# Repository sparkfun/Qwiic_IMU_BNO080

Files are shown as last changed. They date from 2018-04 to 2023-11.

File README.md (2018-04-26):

SparkFun Qwiic VR IMU with the BNO080
========================================

SparkFun Inertial Measurement Unit - BNO080

[*SparkX IMU BNO080 (BOB-14686)*](https://www.sparkfun.com/products/14686)

The BNO080/BNO085 IMU has a combination triple axis accelerometer/gyro/magnetometer packaged with an ARM Cortex M0+ running powerful algorithms. This enables the BNO080 Inertial Measurement Unit (IMU) to produce accurate rotation vector headings with an error of 5 degrees or less. It's what we've been waiting for: all the sensor data is combined into meaningful, accurate IMU information.

This IC was designed to be implemented in Android based cellular phones to handle all the computations necessary for virtual reality goggles using only your phone. The sensor is quite powerful but with power comes a complex interface. We've written an I<sup>2</sup>C based library that provides the rotation vector (the reading most folks want from an IMU) as well as raw acceleration, gyro, and magnetometer readings. The sensor is capable of communicating over SPI and UART as well!

In addition the BNO080 IMU provides a built-in step counter, tap detector, activity classifier (are you running, walking, or sitting still?), and a shake detector. We are duly impressed.

Repository Contents
-------------------

* **/Documents** - Datasheets
* **/Firmware** - Just the test routine for the testjig. Please see the [BNO080/BNO085 library](https://github.com/sparkfun/SparkFun_BNO080_Arduino_Library) for a large number of examples.
* **/Hardware** - Eagle design files (.brd, .sch)
* **/Software** - Processing Example showing how to manipulate graphics using quaternions

Library
--------------
* **[Arduino Library](https://github.com/sparkfun/SparkFun_BNO080_Arduino_Library)** - Library for reading Quaternions, raw accel/gyro/mag, reading activity classifier, advanced configuration, etc.

License Information
-------------------

This product is _**open source**_! 

Please review the LICENSE.md file for license information. 

If you have any questions or concerns on licensing, please contact techsupport@sparkfun.com.

Please use, reuse, and modify these files as you see fit. Please maintain attribution to SparkFun Electronics and release anyThing Development Board derivative under the same license.

Distributed as-is; no warranty is given.

- Your friends at SparkFun.

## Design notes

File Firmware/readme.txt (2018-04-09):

Please download the Arduino library using the library manager for lots of easy to use examples: https://github.com/sparkfun/SparkFun_BNO080_Arduino_Library

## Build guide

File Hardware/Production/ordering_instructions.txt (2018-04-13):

panel size, 262x143mm
PCB thickness, 1.6mm
number of layers, 2
soldermask color, Red
silkscreen color, White
oz copper, 1oz
finish, HASL lead free
stencils, top+bottom

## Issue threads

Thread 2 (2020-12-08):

Python library

JonnyTech, 2020-12-08:
I want to use this board connected to the I2C bus on a Raspberry Pi - is there a Python library available?

mcberry23, 2021-01-24:
This library developed by Adafruit also works on the SparkFun breakout: https://github.com/adafruit/Adafruit_CircuitPython_BNO08x

JonnyTech, 2021-01-24:
Thank you.

Closed 2021-01-24.

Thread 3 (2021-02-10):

Add PWR LED jumper

adamgarbo, 2021-02-10:
Hi folks,

If this board ever gets an upgrade to the Hillcrest (now CEVA) BNO085 or sees a hardware revision, it'd be great to have a jumper added to disable the power LED. I suspect this board was originally designed before this was standard practice at SparkFun.

Cheers,
Adam

adamgarbo, 2021-12-23:
Closing this issue as it is anticipated that any future BNO080/85 boards will include the appropriate LED jumper, which has become part of the standard design of almost all SparkFun products.

Closed 2021-12-23.

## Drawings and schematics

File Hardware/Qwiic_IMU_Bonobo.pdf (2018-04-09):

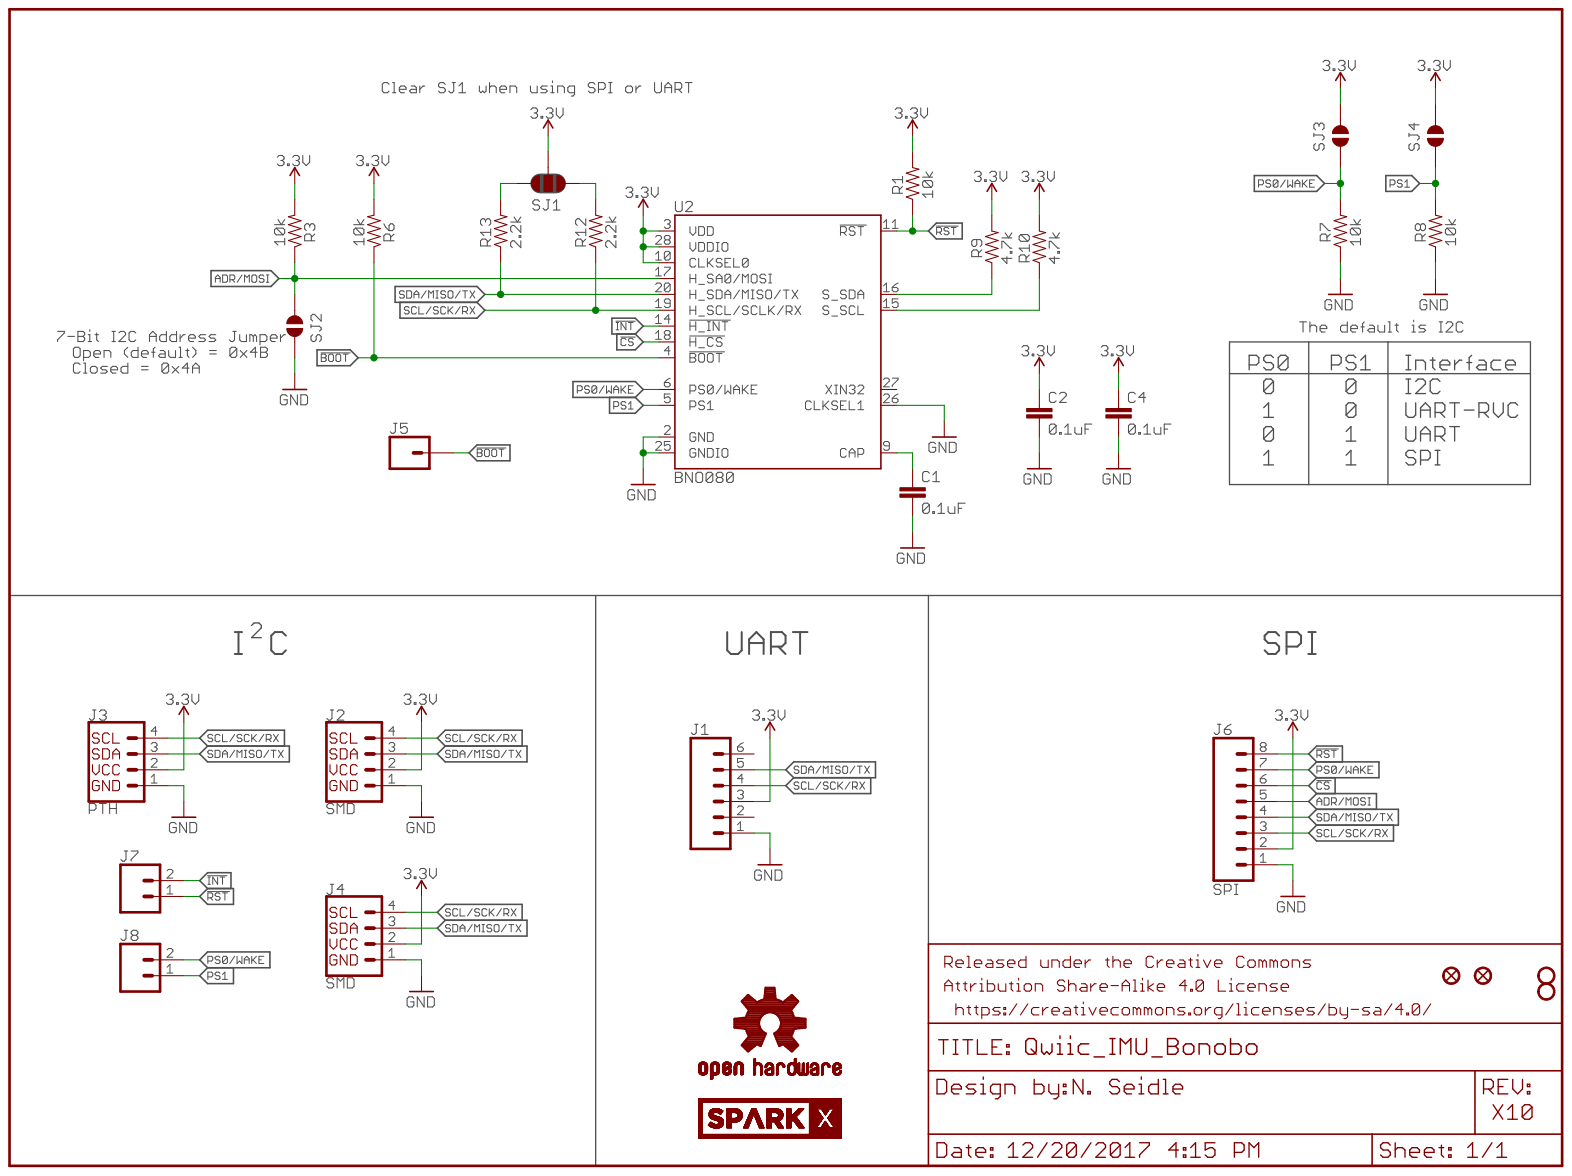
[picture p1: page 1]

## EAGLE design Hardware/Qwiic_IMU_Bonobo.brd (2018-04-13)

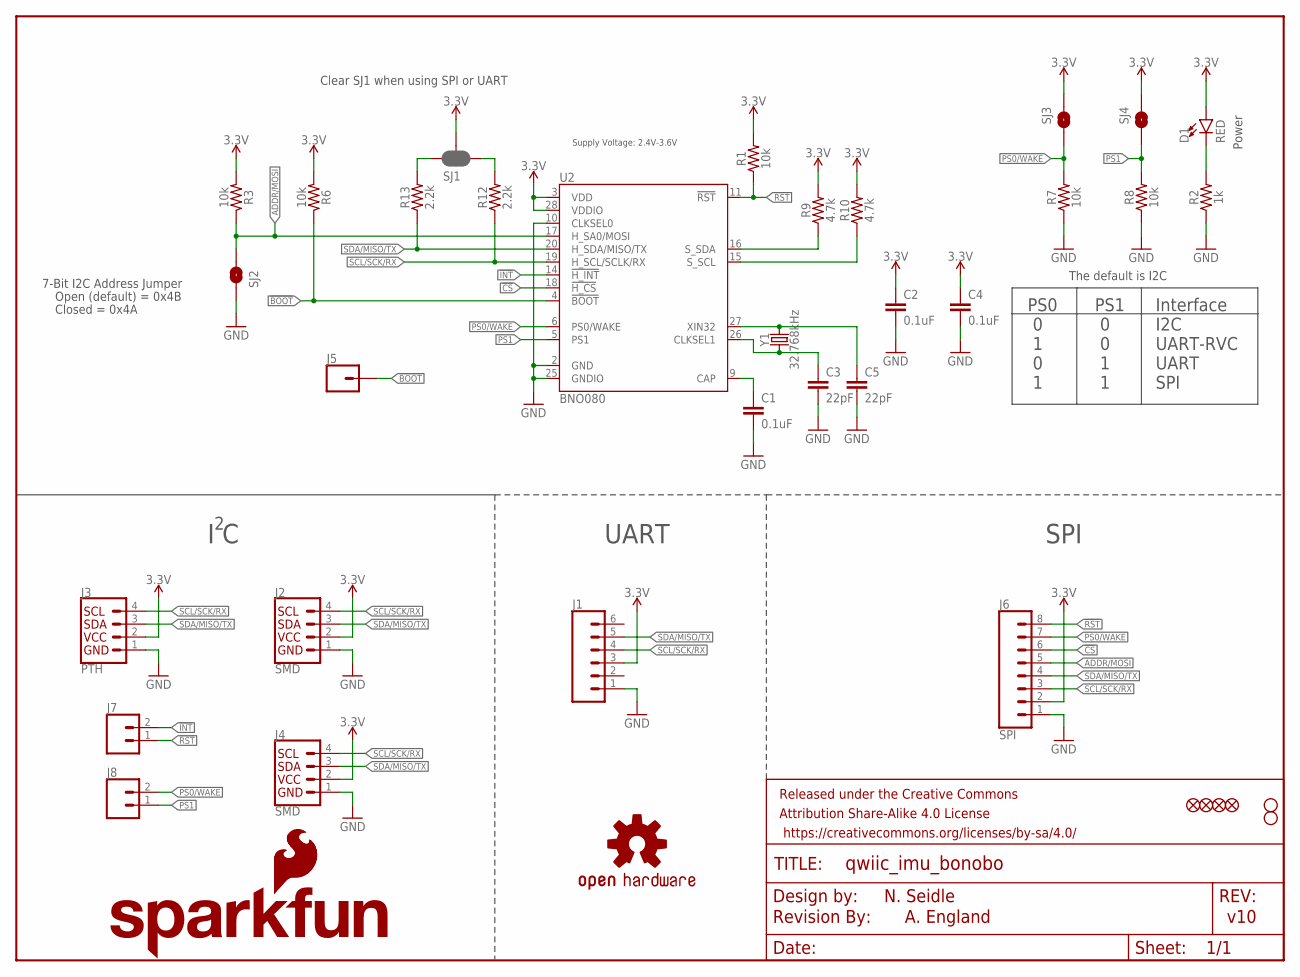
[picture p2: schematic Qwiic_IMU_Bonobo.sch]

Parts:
C1, C2, C4: 0.1uF; 0603
C3, C5: 22pF; 0603
D1: RED; LED-0603
FRAME1: FRAME-LETTER; CREATIVE_COMMONS
J1: CONN_06NO_SILK_FEMALE_PTH; 1X06_NO_SILK
J2, J4: SMD; 1X04_1MM_RA
J3: PTH; 1X04_NO_SILK
J5: CONN_01PTH_NO_SILK_YES_STOP; 1X01_NO_SILK
J6: SPI; 1X08_NO_SILK
J7, J8: CONN_021X02_NO_SILK; 1X02_NO_SILK
JP1, JP2, JP5, JP6: FIDUCIALUFIDUCIAL; MICRO-FIDUCIAL
JP3, JP4: STAND-OFF
LOGO1: OSHW-LOGOMINI; OSHW-LOGO-MINI
LOGO2: REVISION
LOGO4: SFE_LOGO_FLAME.1_INCH; SFE_LOGO_FLAME_.1
LOGO5: SFE_LOGO_NAME_FLAME.1_INCH; SFE_LOGO_NAME_FLAME_.1
R1, R3, R6, R7, R8: 10k; 0603
R2: 1k; 0603
R9, R10: 4.7k; 0603
R12, R13: 2.2k; 0603
SJ1: JUMPER-SMT_3_2-NC_PASTE_SILK; SMT-JUMPER_3_2-NC_PASTE_SILK
SJ2, SJ3, SJ4: SOLDERJUMPERNO; SJ_2S-NO
U2: BNO080; LGA-28
Y1: 32.768kHz; CRYSTAL-SMD-3.2X1.5MM

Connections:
3.3V: C2.1, C4.1, D1.A, J1.3, J2.2 (VCC), J3.2 (VCC), J4.2 (VCC), J6.2, R1.2, R3.2, R6.2, R9.2, R10.2, SJ1.2, SJ3.1, SJ4.1, U2.3 (VDD), U2.28 (VDDIO)
!BOOT: J5.1, R6.1, U2.4 (!BOOT)
!CS: J6.6, U2.18 (!H_CS)
!INT: J7.2, U2.14 (!H_INT)
!RST: J6.8, J7.1, R1.1, U2.11 (!RST)
ADDR/MOSI: J6.5, R3.1, SJ2.2, U2.17 (H_SA0/MOSI)
CAP: C1.1, U2.9 (CAP)
GND: C1.2, C2.2, C3.2, C4.2, C5.2, J1.1, J2.1 (GND), J3.1 (GND), J4.1 (GND), J6.1, R2.1, R7.1, R8.1, SJ2.1, U2.2 (GND), U2.10 (CLKSEL0), U2.25 (GNDIO)
unnamed: C5.1, U2.27 (XIN32), Y1.P$2 (2)
unnamed: C3.1, U2.26 (CLKSEL1), Y1.P$1 (1)
unnamed: D1.C, R2.2
PS0/WAKE: J6.7, J8.2, R7.2, SJ3.2, U2.6 (PS0/WAKE)
PS1: J8.1, R8.2, SJ4.2, U2.5 (PS1)
SCL/SCK/RX: J1.4, J2.4 (SCL), J3.4 (SCL), J4.4 (SCL), J6.3, R12.1, U2.19 (H_SCL/SCLK/RX)
SCL_PU: R12.2, SJ1.1
SDA/MISO/TX: J1.5, J2.3 (SDA), J3.3 (SDA), J4.3 (SDA), J6.4, R13.1, U2.20 (H_SDA/MISO/TX)
SDA_PU: R13.2, SJ1.3
S_SCL: R10.1, U2.15 (S_SCL)
S_SDA: R9.1, U2.16 (S_SDA)

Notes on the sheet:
N. Seidle
v10
7-Bit I2C Address Jumper
Closed = 0x4A
Open (default) = 0x4B
PS0 0 1 0 1
PS1 0 0 1 1
Interface I2C UART-RVC UART SPI
The default is I2C
Clear SJ1 when using SPI or UART
I C
UART
SPI
Power
A. England
Supply Voltage: 2.4V-3.6V

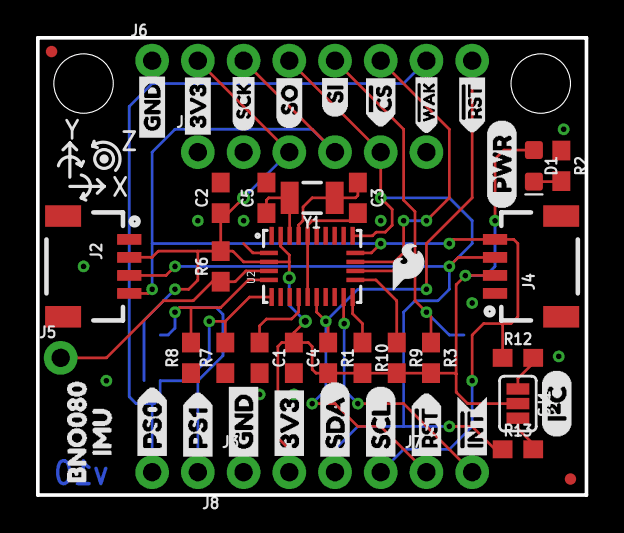
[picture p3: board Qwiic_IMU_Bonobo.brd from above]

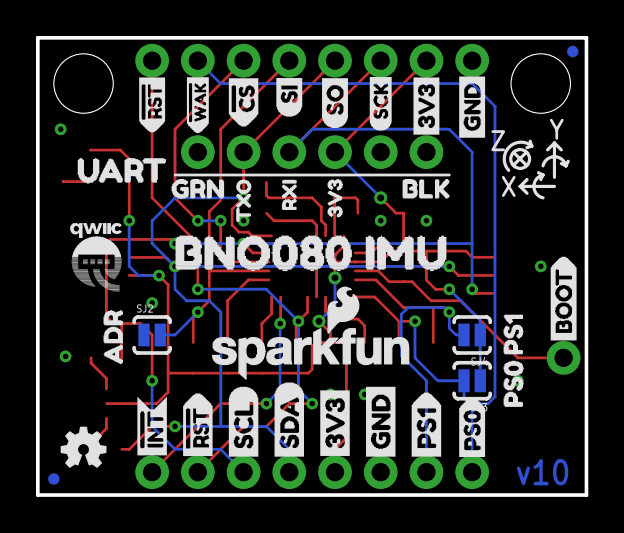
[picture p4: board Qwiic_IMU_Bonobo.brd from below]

Board: 2 copper layers, 30.5 x 25.4 mm, 89 parts (35 on the bottom side), 19 nets.

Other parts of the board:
U$1: (PWR)
U$2: BOOT2
U$3, U$4: #RST>
U$5, U$6: SCL
U$7, U$8: SDA
U$9, U$10: 3V3
U$11, U$50: 3V30
U$12, U$13: SCK0
U$14: PS03
U$15, U$16: GND
U$17, U$18: SI1
U$19, U$20: #WAK6
U$21: 3V32
U$22: RXI1
U$23: (I_SUPER2_C)
U$25, U$26: #INT0
U$27, U$28: PS14
U$29: PS05
U$30: ADR0
U$33: PS114
U$34: PS015
U$35: TXO0
U$39: UART8
U$40: GRN10
U$41: BLK9
U$42, U$43: GND1
U$44: BNO080_IMU11
U$46: BNO08012
U$47: IMU13
U$49, U$51: #RST7
U$52, U$53: #CS3
U$54, U$55: SO0
U$59: QWIIC#LABEL#FULL#M#PNG

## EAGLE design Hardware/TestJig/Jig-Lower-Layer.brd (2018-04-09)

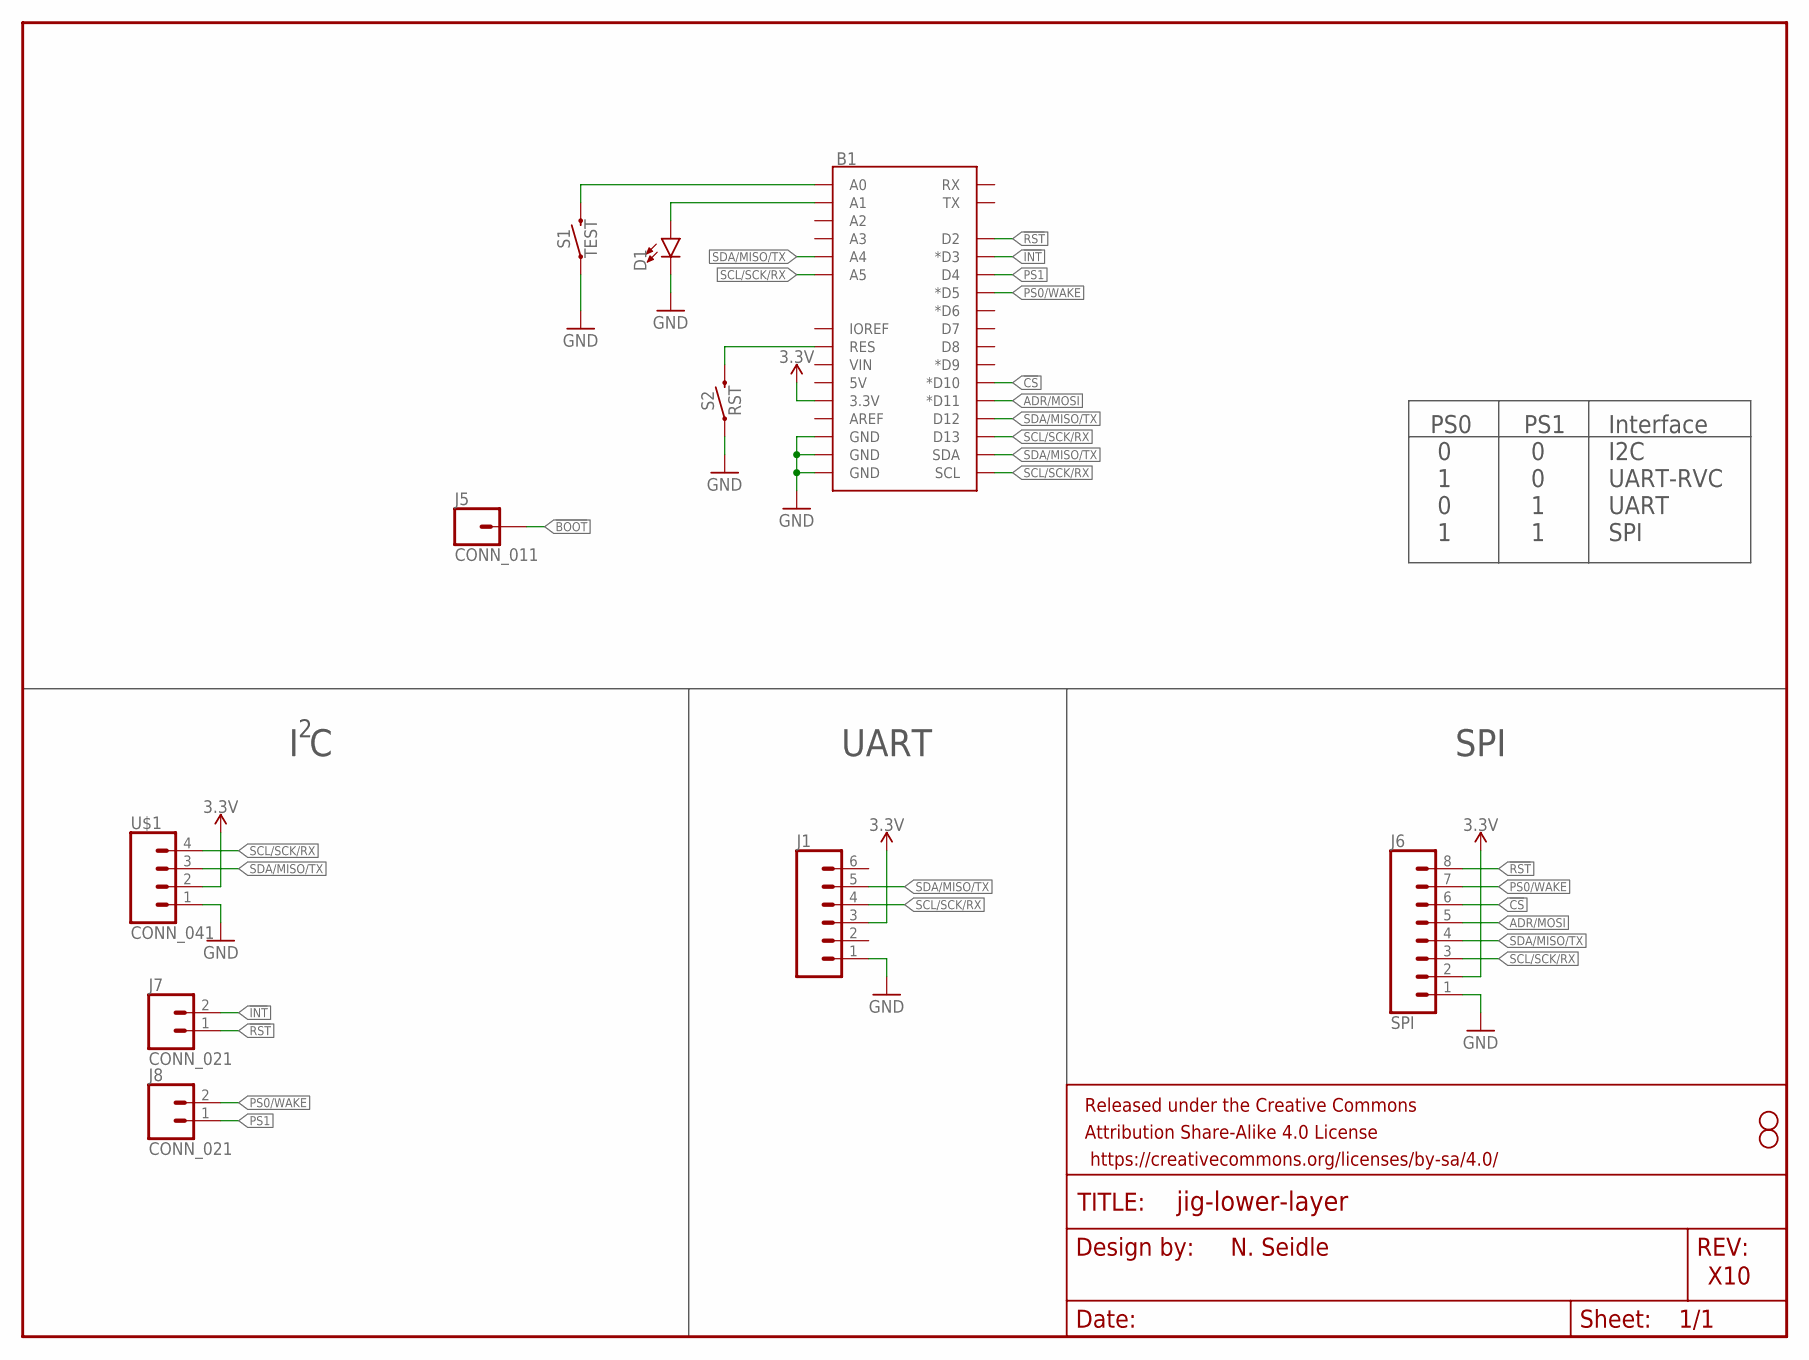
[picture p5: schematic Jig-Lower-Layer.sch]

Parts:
B1: ARDUINO_UNO_R3_SHIELDBASIC; UNO_R3_SHIELD
D1: LED5MM; LED_5MM
FRAME1: FRAME-LETTER; CREATIVE_COMMONS
J1: CONN_061; 1X06
J5: CONN_011; 1X01
J6: SPI; 1X08
J7, J8: CONN_021; 1X02
JP3, JP4: STAND-OFF
S1: TEST; TACTILE_SWITCH_PTH_12MM
S2: RST; TACTILE_SWITCH_PTH_12MM
U$1: CONN_041; 1X04

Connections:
3.3V: B1.3.3V, J1.3, J6.2, U$1.2
!BOOT: J5.1
!CS: B1.D10 (*D10), J6.6
!INT: B1.D3 (*D3), J7.2
!RST: B1.D2, J6.8, J7.1
ADR/MOSI: B1.D11 (*D11), J6.5
GND: B1.GND@0 (GND), B1.GND@1 (GND), B1.GND@2 (GND), D1.K (C), J1.1, J6.1, S1.1, S2.1, U$1.1
unnamed: B1.A0, S1.3 (2)
unnamed: B1.A1, D1.A
unnamed: B1.RES, S2.3 (2)
PS0/WAKE: B1.D5 (*D5), J6.7, J8.2
PS1: B1.D4, J8.1
SCL/SCK/RX: B1.A5, B1.D13, B1.SCL, J1.4, J6.3, U$1.4
SDA/MISO/TX: B1.A4, B1.D12, B1.SDA, J1.5, J6.4, U$1.3

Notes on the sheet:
N. Seidle
X10
PS0 0 1 0 1
PS1 0 0 1 1
Interface I2C UART-RVC UART SPI
I C
UART
SPI

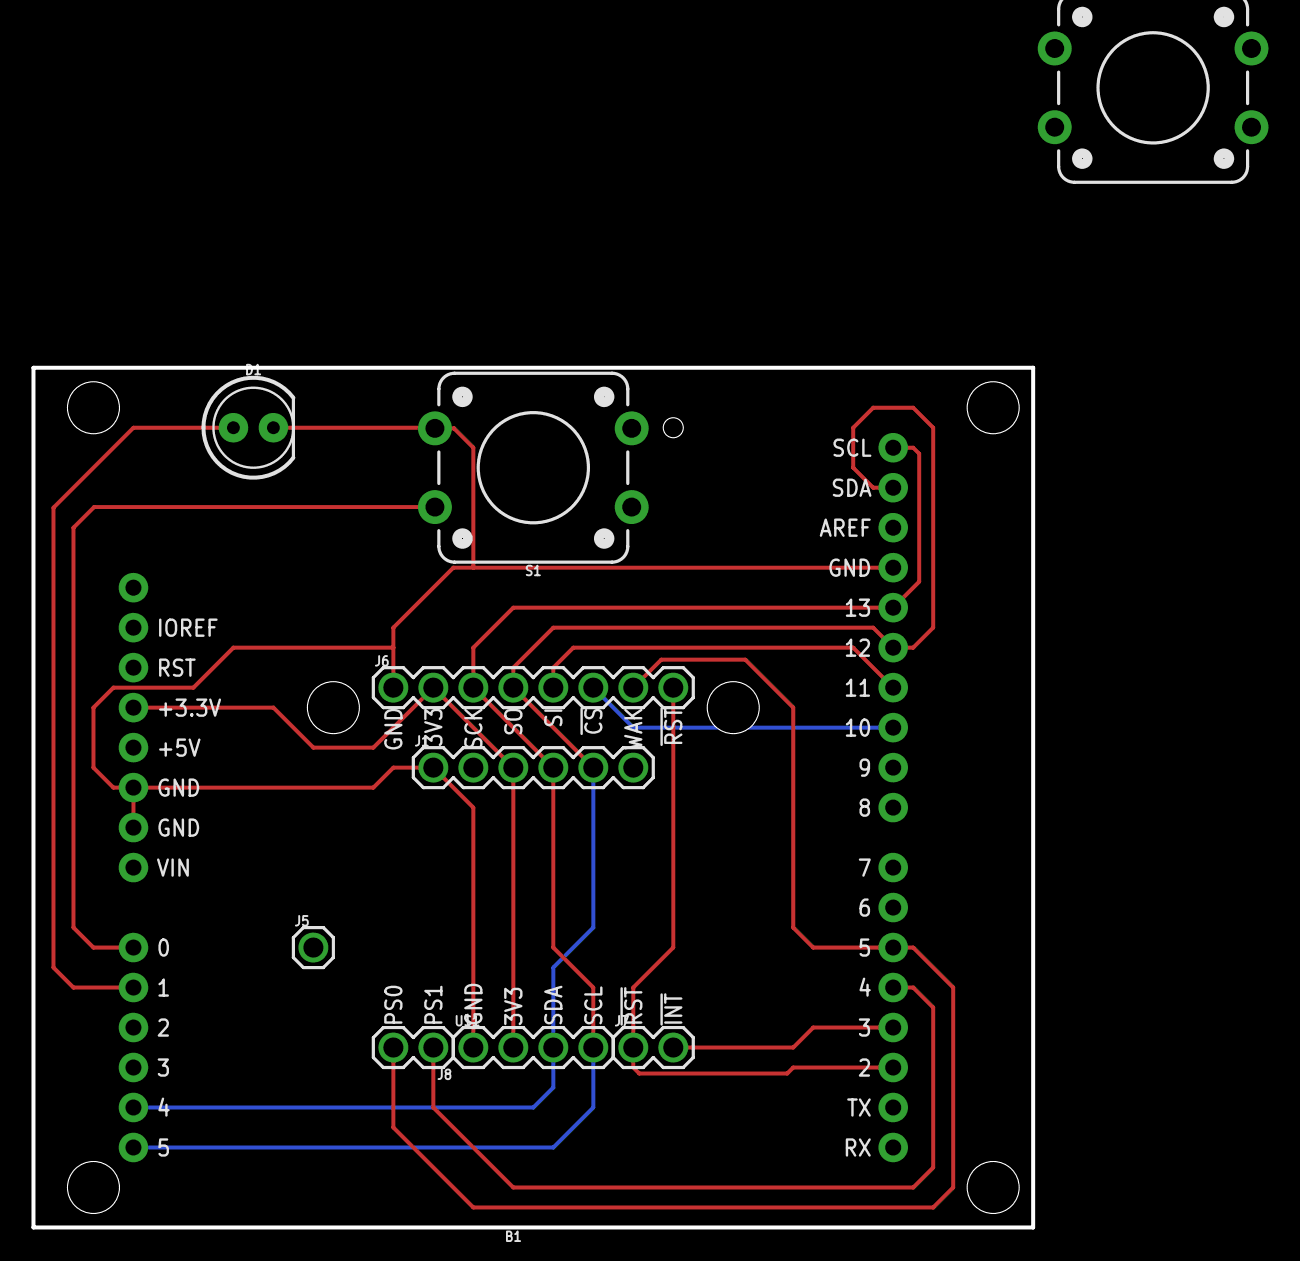
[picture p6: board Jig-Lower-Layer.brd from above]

Board: 2 copper layers, 63.5 x 54.6 mm, 17 parts (0 on the bottom side), 13 nets.

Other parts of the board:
JP1, JP2, JP5, JP6: STAND-OFF

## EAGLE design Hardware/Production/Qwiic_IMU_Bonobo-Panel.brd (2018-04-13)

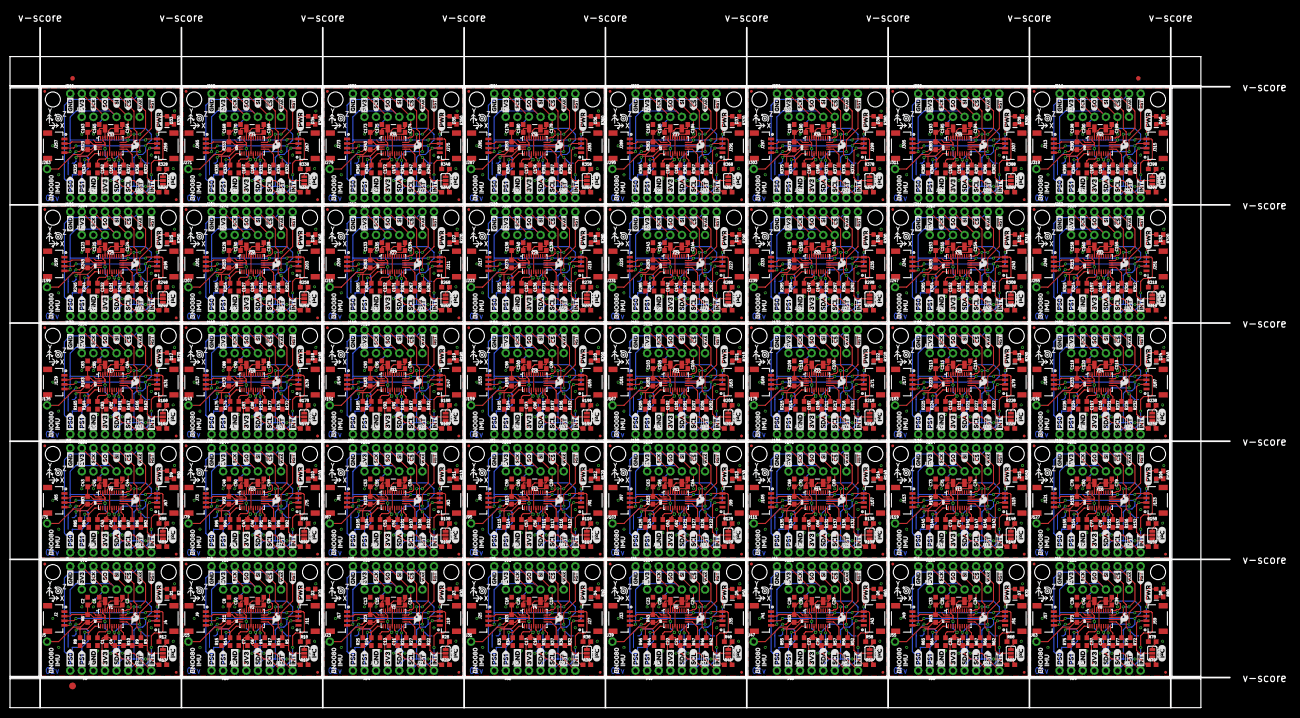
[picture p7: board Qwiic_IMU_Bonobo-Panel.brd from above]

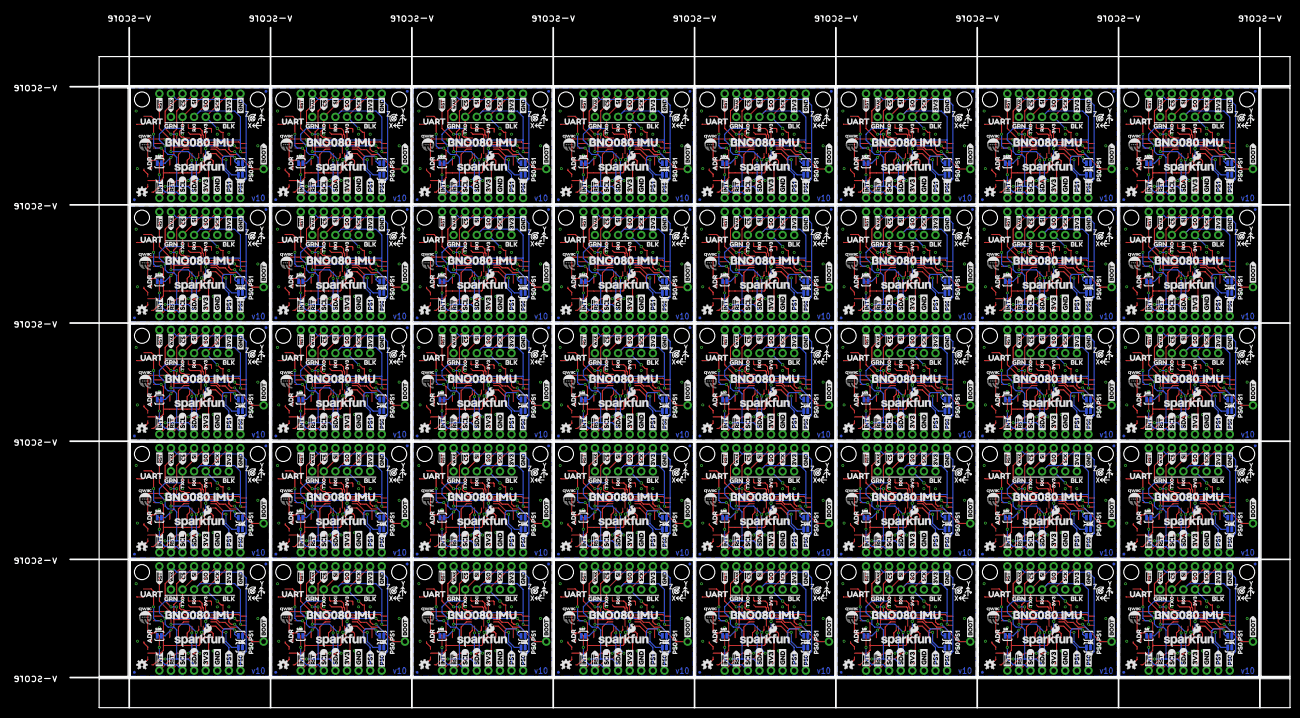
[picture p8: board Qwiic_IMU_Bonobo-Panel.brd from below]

Board: 2 copper layers, 267.5 x 149.1 mm, 3483 parts (1400 on the bottom side), 760 nets.

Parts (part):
C1, C2, C4, C6, C7, C8, C11, C12, C13, C16, C17, C18, C21, C22, C23, C26, C27, C28, C31, C32, C33, C36, C37, C38, C41, C42, C43, C46, C47, C48, C51, C52, C53, C56, C57, C58, C61, C62, C63, C66, C67, C68, C71, C72, C73, C76, C77, C78, C81, C82, C83, C86, C87, C88, C91, C92, C93, C96, C97, C98, C101, C102, C103, C106, C107, C108, C111, C112, C113, C116, C117, C118, C121, C122, C123, C126, C127, C128, C131, C132, C133, C136, C137, C138, C141, C142, C143, C146, C147, C148, C151, C152, C153, C156, C157, C158, C161, C162, C163, C166, C167, C168, C171, C172, C173, C176, C177, C178, C181, C182, C183, C186, C187, C188, C191, C192, C193, C196, C197, C198: 0.1uF; 0603
C3, C5, C9, C10, C14, C15, C19, C20, C24, C25, C29, C30, C34, C35, C39, C40, C44, C45, C49, C50, C54, C55, C59, C60, C64, C65, C69, C70, C74, C75, C79, C80, C84, C85, C89, C90, C94, C95, C99, C100, C104, C105, C109, C110, C114, C115, C119, C120, C124, C125, C129, C130, C134, C135, C139, C140, C144, C145, C149, C150, C154, C155, C159, C160, C164, C165, C169, C170, C174, C175, C179, C180, C184, C185, C189, C190, C194, C195, C199, C200: 22pF; 0603
D1, D2, D3, D4, D5, D6, D7, D8, D9, D10, D11, D12, D13, D14, D15, D16, D17, D18, D19, D20, D21, D22, D23, D24, D25, D26, D27, D28, D29, D30, D31, D32, D33, D34, D35, D36, D37, D38, D39, D40: RED; LED-0603
E$1, E$2: FIDUCIAL-1X2
E$3: FIDUCIAL-1.5X3
J1, J14, J22, J30, J38, J46, J54, J62, J70, J78, J86, J94, J102, J110, J118, J126, J134, J142, J150, J158, J166, J174, J182, J190, J198, J206, J214, J222, J230, J238, J246, J254, J262, J270, J278, J286, J294, J302, J310, J318: 1X06_NO_SILK
J2, J4, J9, J11, J17, J19, J25, J27, J33, J35, J41, J43, J49, J51, J57, J59, J65, J67, J73, J75, J81, J83, J89, J91, J97, J99, J105, J107, J113, J115, J121, J123, J129, J131, J137, J139, J145, J147, J153, J155, J161, J163, J169, J171, J177, J179, J185, J187, J193, J195, J201, J203, J209, J211, J217, J219, J225, J227, J233, J235, J241, J243, J249, J251, J257, J259, J265, J267, J273, J275, J281, J283, J289, J291, J297, J299, J305, J307, J313, J315: SMD; 1X04_1MM_RA
J3, J10, J18, J26, J34, J42, J50, J58, J66, J74, J82, J90, J98, J106, J114, J122, J130, J138, J146, J154, J162, J170, J178, J186, J194, J202, J210, J218, J226, J234, J242, J250, J258, J266, J274, J282, J290, J298, J306, J314: PTH; 1X04_NO_SILK
J5, J15, J23, J31, J39, J47, J55, J63, J71, J79, J87, J95, J103, J111, J119, J127, J135, J143, J151, J159, J167, J175, J183, J191, J199, J207, J215, J223, J231, J239, J247, J255, J263, J271, J279, J287, J295, J303, J311, J319: 1X01_NO_SILK
J6, J12, J20, J28, J36, J44, J52, J60, J68, J76, J84, J92, J100, J108, J116, J124, J132, J140, J148, J156, J164, J172, J180, J188, J196, J204, J212, J220, J228, J236, J244, J252, J260, J268, J276, J284, J292, J300, J308, J316: SPI; 1X08_NO_SILK
J7, J8, J13, J16, J21, J24, J29, J32, J37, J40, J45, J48, J53, J56, J61, J64, J69, J72, J77, J80, J85, J88, J93, J96, J101, J104, J109, J112, J117, J120, J125, J128, J133, J136, J141, J144, J149, J152, J157, J160, J165, J168, J173, J176, J181, J184, J189, J192, J197, J200, J205, J208, J213, J216, J221, J224, J229, J232, J237, J240, J245, J248, J253, J256, J261, J264, J269, J272, J277, J280, J285, J288, J293, J296, J301, J304, J309, J312, J317, J320: 1X02_NO_SILK
JP1, JP2, JP5, JP6, JP9, JP10, JP11, JP12, JP15, JP16, JP17, JP18, JP21, JP22, JP23, JP24, JP27, JP28, JP29, JP30, JP33, JP34, JP35, JP36, JP39, JP40, JP41, JP42, JP45, JP46, JP47, JP48, JP51, JP52, JP53, JP54, JP57, JP58, JP59, JP60, JP63, JP64, JP65, JP66, JP69, JP70, JP71, JP72, JP75, JP76, JP77, JP78, JP81, JP82, JP83, JP84, JP87, JP88, JP89, JP90, JP93, JP94, JP95, JP96, JP99, JP100, JP101, JP102, JP105, JP106, JP107, JP108, JP111, JP112, JP113, JP114, JP117, JP118, JP119, JP120, JP123, JP124, JP125, JP126, JP129, JP130, JP131, JP132, JP135, JP136, JP137, JP138, JP141, JP142, JP143, JP144, JP147, JP148, JP149, JP150, JP153, JP154, JP155, JP156, JP159, JP160, JP161, JP162, JP165, JP166, JP167, JP168, JP171, JP172, JP173, JP174, JP177, JP178, JP179, JP180, JP183, JP184, JP185, JP186, JP189, JP190, JP191, JP192, JP195, JP196, JP197, JP198, JP201, JP202, JP203, JP204, JP207, JP208, JP209, JP210, JP213, JP214, JP215, JP216, JP219, JP220, JP221, JP222, JP225, JP226, JP227, JP228, JP231, JP232, JP233, JP234, JP237, JP238, JP239, JP240: FIDUCIALUFIDUCIAL; MICRO-FIDUCIAL
JP3, JP4, JP7, JP8, JP13, JP14, JP19, JP20, JP25, JP26, JP31, JP32, JP37, JP38, JP43, JP44, JP49, JP50, JP55, JP56, JP61, JP62, JP67, JP68, JP73, JP74, JP79, JP80, JP85, JP86, JP91, JP92, JP97, JP98, JP103, JP104, JP109, JP110, JP115, JP116, JP121, JP122, JP127, JP128, JP133, JP134, JP139, JP140, JP145, JP146, JP151, JP152, JP157, JP158, JP163, JP164, JP169, JP170, JP175, JP176, JP181, JP182, JP187, JP188, JP193, JP194, JP199, JP200, JP205, JP206, JP211, JP212, JP217, JP218, JP223, JP224, JP229, JP230, JP235, JP236: STAND-OFF
LOGO1, LOGO2, LOGO7, LOGO10, LOGO13, LOGO16, LOGO19, LOGO22, LOGO25, LOGO28, LOGO31, LOGO34, LOGO37, LOGO40, LOGO43, LOGO46, LOGO49, LOGO52, LOGO55, LOGO58, LOGO61, LOGO64, LOGO67, LOGO70, LOGO73, LOGO76, LOGO79, LOGO82, LOGO85, LOGO88, LOGO91, LOGO94, LOGO97, LOGO100, LOGO103, LOGO106, LOGO109, LOGO112, LOGO115, LOGO118: OSHW-LOGOMINI; OSHW-LOGO-MINI
LOGO3, LOGO4, LOGO8, LOGO11, LOGO14, LOGO17, LOGO20, LOGO23, LOGO26, LOGO29, LOGO32, LOGO35, LOGO38, LOGO41, LOGO44, LOGO47, LOGO50, LOGO53, LOGO56, LOGO59, LOGO62, LOGO65, LOGO68, LOGO71, LOGO74, LOGO77, LOGO80, LOGO83, LOGO86, LOGO89, LOGO92, LOGO95, LOGO98, LOGO101, LOGO104, LOGO107, LOGO110, LOGO113, LOGO116, LOGO119: SFE_LOGO_FLAME.1_INCH; SFE_LOGO_FLAME_.1
LOGO5, LOGO6, LOGO9, LOGO12, LOGO15, LOGO18, LOGO21, LOGO24, LOGO27, LOGO30, LOGO33, LOGO36, LOGO39, LOGO42, LOGO45, LOGO48, LOGO51, LOGO54, LOGO57, LOGO60, LOGO63, LOGO66, LOGO69, LOGO72, LOGO75, LOGO78, LOGO81, LOGO84, LOGO87, LOGO90, LOGO93, LOGO96, LOGO99, LOGO102, LOGO105, LOGO108, LOGO111, LOGO114, LOGO117, LOGO120: SFE_LOGO_NAME_FLAME.1_INCH; SFE_LOGO_NAME_FLAME_.1
R1, R3, R4, R5, R6, R7, R8, R11, R14, R15, R21, R22, R23, R24, R25, R31, R32, R33, R34, R35, R41, R42, R43, R44, R45, R51, R52, R53, R54, R55, R61, R62, R63, R64, R65, R71, R72, R73, R74, R75, R81, R82, R83, R84, R85, R91, R92, R93, R94, R95, R101, R102, R103, R104, R105, R111, R112, R113, R114, R115, R121, R122, R123, R124, R125, R131, R132, R133, R134, R135, R141, R142, R143, R144, R145, R151, R152, R153, R154, R155, R161, R162, R163, R164, R165, R171, R172, R173, R174, R175, R181, R182, R183, R184, R185, R191, R192, R193, R194, R195, R201, R202, R203, R204, R205, R211, R212, R213, R214, R215, R221, R222, R223, R224, R225, R231, R232, R233, R234, R235, R241, R242, R243, R244, R245, R251, R252, R253, R254, R255, R261, R262, R263, R264, R265, R271, R272, R273, R274, R275, R281, R282, R283, R284, R285, R291, R292, R293, R294, R295, R301, R302, R303, R304, R305, R311, R312, R313, R314, R315, R321, R322, R323, R324, R325, R331, R332, R333, R334, R335, R341, R342, R343, R344, R345, R351, R352, R353, R354, R355, R361, R362, R363, R364, R365, R371, R372, R373, R374, R375, R381, R382, R383, R384, R385, R391, R392, R393, R394, R395: 10k; 0603
R2, R20, R30, R40, R50, R60, R70, R80, R90, R100, R110, R120, R130, R140, R150, R160, R170, R180, R190, R200, R210, R220, R230, R240, R250, R260, R270, R280, R290, R300, R310, R320, R330, R340, R350, R360, R370, R380, R390, R400: 1k; 0603
R9, R10, R16, R17, R26, R27, R36, R37, R46, R47, R56, R57, R66, R67, R76, R77, R86, R87, R96, R97, R106, R107, R116, R117, R126, R127, R136, R137, R146, R147, R156, R157, R166, R167, R176, R177, R186, R187, R196, R197, R206, R207, R216, R217, R226, R227, R236, R237, R246, R247, R256, R257, R266, R267, R276, R277, R286, R287, R296, R297, R306, R307, R316, R317, R326, R327, R336, R337, R346, R347, R356, R357, R366, R367, R376, R377, R386, R387, R396, R397: 4.7k; 0603
R12, R13, R18, R19, R28, R29, R38, R39, R48, R49, R58, R59, R68, R69, R78, R79, R88, R89, R98, R99, R108, R109, R118, R119, R128, R129, R138, R139, R148, R149, R158, R159, R168, R169, R178, R179, R188, R189, R198, R199, R208, R209, R218, R219, R228, R229, R238, R239, R248, R249, R258, R259, R268, R269, R278, R279, R288, R289, R298, R299, R308, R309, R318, R319, R328, R329, R338, R339, R348, R349, R358, R359, R368, R369, R378, R379, R388, R389, R398, R399: 2.2k; 0603
SJ1, SJ8, SJ12, SJ16, SJ20, SJ24, SJ28, SJ32, SJ36, SJ40, SJ44, SJ48, SJ52, SJ56, SJ60, SJ64, SJ68, SJ72, SJ76, SJ80, SJ84, SJ88, SJ92, SJ96, SJ100, SJ104, SJ108, SJ112, SJ116, SJ120, SJ124, SJ128, SJ132, SJ136, SJ140, SJ144, SJ148, SJ152, SJ156, SJ160: SMT-JUMPER_3_2-NC_PASTE_SILK
SJ2, SJ3, SJ4, SJ5, SJ6, SJ7, SJ9, SJ10, SJ11, SJ13, SJ14, SJ15, SJ17, SJ18, SJ19, SJ21, SJ22, SJ23, SJ25, SJ26, SJ27, SJ29, SJ30, SJ31, SJ33, SJ34, SJ35, SJ37, SJ38, SJ39, SJ41, SJ42, SJ43, SJ45, SJ46, SJ47, SJ49, SJ50, SJ51, SJ53, SJ54, SJ55, SJ57, SJ58, SJ59, SJ61, SJ62, SJ63, SJ65, SJ66, SJ67, SJ69, SJ70, SJ71, SJ73, SJ74, SJ75, SJ77, SJ78, SJ79, SJ81, SJ82, SJ83, SJ85, SJ86, SJ87, SJ89, SJ90, SJ91, SJ93, SJ94, SJ95, SJ97, SJ98, SJ99, SJ101, SJ102, SJ103, SJ105, SJ106, SJ107, SJ109, SJ110, SJ111, SJ113, SJ114, SJ115, SJ117, SJ118, SJ119, SJ121, SJ122, SJ123, SJ125, SJ126, SJ127, SJ129, SJ130, SJ131, SJ133, SJ134, SJ135, SJ137, SJ138, SJ139, SJ141, SJ142, SJ143, SJ145, SJ146, SJ147, SJ149, SJ150, SJ151, SJ153, SJ154, SJ155, SJ157, SJ158, SJ159: SJ_2S-NO
U1, U2, U3, U4, U5, U6, U7, U8, U9, U10, U11, U12, U13, U14, U15, U16, U17, U18, U19, U20, U21, U22, U23, U24, U25, U26, U27, U28, U29, U30, U31, U32, U33, U34, U35, U36, U37, U38, U39, U40: BNO080; LGA-28
U$1, U$95, U$143, U$191, U$239, U$287, U$335, U$383, U$431, U$479, U$527, U$575, U$623, U$671, U$719, U$767, U$815, U$863, U$911, U$959, U$1007, U$1055, U$1103, U$1151, U$1199, U$1247, U$1295, U$1343, U$1391, U$1439, U$1487, U$1535, U$1583, U$1631, U$1679, U$1727, U$1775, U$1823, U$1871, U$1919: (PWR)
U$2, U$94, U$142, U$190, U$238, U$286, U$334, U$382, U$430, U$478, U$526, U$574, U$622, U$670, U$718, U$766, U$814, U$862, U$910, U$958, U$1006, U$1054, U$1102, U$1150, U$1198, U$1246, U$1294, U$1342, U$1390, U$1438, U$1486, U$1534, U$1582, U$1630, U$1678, U$1726, U$1774, U$1822, U$1870, U$1918: BOOT2
U$3, U$4, U$24, U$31, U$97, U$98, U$145, U$146, U$193, U$194, U$241, U$242, U$289, U$290, U$337, U$338, U$385, U$386, U$433, U$434, U$481, U$482, U$529, U$530, U$577, U$578, U$625, U$626, U$673, U$674, U$721, U$722, U$769, U$770, U$817, U$818, U$865, U$866, U$913, U$914, U$961, U$962, U$1009, U$1010, U$1057, U$1058, U$1105, U$1106, U$1153, U$1154, U$1201, U$1202, U$1249, U$1250, U$1297, U$1298, U$1345, U$1346, U$1393, U$1394, U$1441, U$1442, U$1489, U$1490, U$1537, U$1538, U$1585, U$1586, U$1633, U$1634, U$1681, U$1682, U$1729, U$1730, U$1777, U$1778, U$1825, U$1826, U$1873, U$1874: #RST>
U$5, U$6, U$32, U$36, U$99, U$100, U$147, U$148, U$195, U$196, U$243, U$244, U$291, U$292, U$339, U$340, U$387, U$388, U$435, U$436, U$483, U$484, U$531, U$532, U$579, U$580, U$627, U$628, U$675, U$676, U$723, U$724, U$771, U$772, U$819, U$820, U$867, U$868, U$915, U$916, U$963, U$964, U$1011, U$1012, U$1059, U$1060, U$1107, U$1108, U$1155, U$1156, U$1203, U$1204, U$1251, U$1252, U$1299, U$1300, U$1347, U$1348, U$1395, U$1396, U$1443, U$1444, U$1491, U$1492, U$1539, U$1540, U$1587, U$1588, U$1635, U$1636, U$1683, U$1684, U$1731, U$1732, U$1779, U$1780, U$1827, U$1828, U$1875, U$1876: SCL
U$7, U$8, U$37, U$38, U$101, U$102, U$149, U$150, U$197, U$198, U$245, U$246, U$293, U$294, U$341, U$342, U$389, U$390, U$437, U$438, U$485, U$486, U$533, U$534, U$581, U$582, U$629, U$630, U$677, U$678, U$725, U$726, U$773, U$774, U$821, U$822, U$869, U$870, U$917, U$918, U$965, U$966, U$1013, U$1014, U$1061, U$1062, U$1109, U$1110, U$1157, U$1158, U$1205, U$1206, U$1253, U$1254, U$1301, U$1302, U$1349, U$1350, U$1397, U$1398, U$1445, U$1446, U$1493, U$1494, U$1541, U$1542, U$1589, U$1590, U$1637, U$1638, U$1685, U$1686, U$1733, U$1734, U$1781, U$1782, U$1829, U$1830, U$1877, U$1878: SDA
U$9, U$10, U$45, U$48, U$103, U$104, U$151, U$152, U$199, U$200, U$247, U$248, U$295, U$296, U$343, U$344, U$391, U$392, U$439, U$440, U$487, U$488, U$535, U$536, U$583, U$584, U$631, U$632, U$679, U$680, U$727, U$728, U$775, U$776, U$823, U$824, U$871, U$872, U$919, U$920, U$967, U$968, U$1015, U$1016, U$1063, U$1064, U$1111, U$1112, U$1159, U$1160, U$1207, U$1208, U$1255, U$1256, U$1303, U$1304, U$1351, U$1352, U$1399, U$1400, U$1447, U$1448, U$1495, U$1496, U$1543, U$1544, U$1591, U$1592, U$1639, U$1640, U$1687, U$1688, U$1735, U$1736, U$1783, U$1784, U$1831, U$1832, U$1879, U$1880: 3V3
U$11, U$50, U$73, U$74, U$121, U$122, U$169, U$170, U$217, U$218, U$265, U$266, U$313, U$314, U$361, U$362, U$409, U$410, U$457, U$458, U$505, U$506, U$553, U$554, U$601, U$602, U$649, U$650, U$697, U$698, U$745, U$746, U$793, U$794, U$841, U$842, U$889, U$890, U$937, U$938, U$985, U$986, U$1033, U$1034, U$1081, U$1082, U$1129, U$1130, U$1177, U$1178, U$1225, U$1226, U$1273, U$1274, U$1321, U$1322, U$1369, U$1370, U$1417, U$1418, U$1465, U$1466, U$1513, U$1514, U$1561, U$1562, U$1609, U$1610, U$1657, U$1658, U$1705, U$1706, U$1753, U$1754, U$1801, U$1802, U$1849, U$1850, U$1897, U$1898: 3V30
U$12, U$13, U$83, U$84, U$131, U$132, U$179, U$180, U$227, U$228, U$275, U$276, U$323, U$324, U$371, U$372, U$419, U$420, U$467, U$468, U$515, U$516, U$563, U$564, U$611, U$612, U$659, U$660, U$707, U$708, U$755, U$756, U$803, U$804, U$851, U$852, U$899, U$900, U$947, U$948, U$995, U$996, U$1043, U$1044, U$1091, U$1092, U$1139, U$1140, U$1187, U$1188, U$1235, U$1236, U$1283, U$1284, U$1331, U$1332, U$1379, U$1380, U$1427, U$1428, U$1475, U$1476, U$1523, U$1524, U$1571, U$1572, U$1619, U$1620, U$1667, U$1668, U$1715, U$1716, U$1763, U$1764, U$1811, U$1812, U$1859, U$1860, U$1907, U$1908: SCK0
U$14, U$89, U$137, U$185, U$233, U$281, U$329, U$377, U$425, U$473, U$521, U$569, U$617, U$665, U$713, U$761, U$809, U$857, U$905, U$953, U$1001, U$1049, U$1097, U$1145, U$1193, U$1241, U$1289, U$1337, U$1385, U$1433, U$1481, U$1529, U$1577, U$1625, U$1673, U$1721, U$1769, U$1817, U$1865, U$1913: PS03
U$15, U$16, U$56, U$57, U$105, U$106, U$153, U$154, U$201, U$202, U$249, U$250, U$297, U$298, U$345, U$346, U$393, U$394, U$441, U$442, U$489, U$490, U$537, U$538, U$585, U$586, U$633, U$634, U$681, U$682, U$729, U$730, U$777, U$778, U$825, U$826, U$873, U$874, U$921, U$922, U$969, U$970, U$1017, U$1018, U$1065, U$1066, U$1113, U$1114, U$1161, U$1162, U$1209, U$1210, U$1257, U$1258, U$1305, U$1306, U$1353, U$1354, U$1401, U$1402, U$1449, U$1450, U$1497, U$1498, U$1545, U$1546, U$1593, U$1594, U$1641, U$1642, U$1689, U$1690, U$1737, U$1738, U$1785, U$1786, U$1833, U$1834, U$1881, U$1882: GND
U$17, U$18, U$85, U$86, U$133, U$134, U$181, U$182, U$229, U$230, U$277, U$278, U$325, U$326, U$373, U$374, U$421, U$422, U$469, U$470, U$517, U$518, U$565, U$566, U$613, U$614, U$661, U$662, U$709, U$710, U$757, U$758, U$805, U$806, U$853, U$854, U$901, U$902, U$949, U$950, U$997, U$998, U$1045, U$1046, U$1093, U$1094, U$1141, U$1142, U$1189, U$1190, U$1237, U$1238, U$1285, U$1286, U$1333, U$1334, U$1381, U$1382, U$1429, U$1430, U$1477, U$1478, U$1525, U$1526, U$1573, U$1574, U$1621, U$1622, U$1669, U$1670, U$1717, U$1718, U$1765, U$1766, U$1813, U$1814, U$1861, U$1862, U$1909, U$1910: SI1
U$19, U$20, U$77, U$78, U$125, U$126, U$173, U$174, U$221, U$222, U$269, U$270, U$317, U$318, U$365, U$366, U$413, U$414, U$461, U$462, U$509, U$510, U$557, U$558, U$605, U$606, U$653, U$654, U$701, U$702, U$749, U$750, U$797, U$798, U$845, U$846, U$893, U$894, U$941, U$942, U$989, U$990, U$1037, U$1038, U$1085, U$1086, U$1133, U$1134, U$1181, U$1182, U$1229, U$1230, U$1277, U$1278, U$1325, U$1326, U$1373, U$1374, U$1421, U$1422, U$1469, U$1470, U$1517, U$1518, U$1565, U$1566, U$1613, U$1614, U$1661, U$1662, U$1709, U$1710, U$1757, U$1758, U$1805, U$1806, U$1853, U$1854, U$1901, U$1902: #WAK6
U$21, U$90, U$138, U$186, U$234, U$282, U$330, U$378, U$426, U$474, U$522, U$570, U$618, U$666, U$714, U$762, U$810, U$858, U$906, U$954, U$1002, U$1050, U$1098, U$1146, U$1194, U$1242, U$1290, U$1338, U$1386, U$1434, U$1482, U$1530, U$1578, U$1626, U$1674, U$1722, U$1770, U$1818, U$1866, U$1914: 3V32
U$22, U$91, U$139, U$187, U$235, U$283, U$331, U$379, U$427, U$475, U$523, U$571, U$619, U$667, U$715, U$763, U$811, U$859, U$907, U$955, U$1003, U$1051, U$1099, U$1147, U$1195, U$1243, U$1291, U$1339, U$1387, U$1435, U$1483, U$1531, U$1579, U$1627, U$1675, U$1723, U$1771, U$1819, U$1867, U$1915: RXI1
U$23, U$58, U$107, U$155, U$203, U$251, U$299, U$347, U$395, U$443, U$491, U$539, U$587, U$635, U$683, U$731, U$779, U$827, U$875, U$923, U$971, U$1019, U$1067, U$1115, U$1163, U$1211, U$1259, U$1307, U$1355, U$1403, U$1451, U$1499, U$1547, U$1595, U$1643, U$1691, U$1739, U$1787, U$1835, U$1883: (I_SUPER2_C)
U$25, U$26, U$60, U$61, U$108, U$109, U$156, U$157, U$204, U$205, U$252, U$253, U$300, U$301, U$348, U$349, U$396, U$397, U$444, U$445, U$492, U$493, U$540, U$541, U$588, U$589, U$636, U$637, U$684, U$685, U$732, U$733, U$780, U$781, U$828, U$829, U$876, U$877, U$924, U$925, U$972, U$973, U$1020, U$1021, U$1068, U$1069, U$1116, U$1117, U$1164, U$1165, U$1212, U$1213, U$1260, U$1261, U$1308, U$1309, U$1356, U$1357, U$1404, U$1405, U$1452, U$1453, U$1500, U$1501, U$1548, U$1549, U$1596, U$1597, U$1644, U$1645, U$1692, U$1693, U$1740, U$1741, U$1788, U$1789, U$1836, U$1837, U$1884, U$1885: #INT0
U$27, U$28, U$62, U$63, U$110, U$111, U$158, U$159, U$206, U$207, U$254, U$255, U$302, U$303, U$350, U$351, U$398, U$399, U$446, U$447, U$494, U$495, U$542, U$543, U$590, U$591, U$638, U$639, U$686, U$687, U$734, U$735, U$782, U$783, U$830, U$831, U$878, U$879, U$926, U$927, U$974, U$975, U$1022, U$1023, U$1070, U$1071, U$1118, U$1119, U$1166, U$1167, U$1214, U$1215, U$1262, U$1263, U$1310, U$1311, U$1358, U$1359, U$1406, U$1407, U$1454, U$1455, U$1502, U$1503, U$1550, U$1551, U$1598, U$1599, U$1646, U$1647, U$1694, U$1695, U$1742, U$1743, U$1790, U$1791, U$1838, U$1839, U$1886, U$1887: PS14
U$29, U$64, U$112, U$160, U$208, U$256, U$304, U$352, U$400, U$448, U$496, U$544, U$592, U$640, U$688, U$736, U$784, U$832, U$880, U$928, U$976, U$1024, U$1072, U$1120, U$1168, U$1216, U$1264, U$1312, U$1360, U$1408, U$1456, U$1504, U$1552, U$1600, U$1648, U$1696, U$1744, U$1792, U$1840, U$1888: PS05
U$30, U$93, U$141, U$189, U$237, U$285, U$333, U$381, U$429, U$477, U$525, U$573, U$621, U$669, U$717, U$765, U$813, U$861, U$909, U$957, U$1005, U$1053, U$1101, U$1149, U$1197, U$1245, U$1293, U$1341, U$1389, U$1437, U$1485, U$1533, U$1581, U$1629, U$1677, U$1725, U$1773, U$1821, U$1869, U$1917: ADR0
U$33, U$65, U$113, U$161, U$209, U$257, U$305, U$353, U$401, U$449, U$497, U$545, U$593, U$641, U$689, U$737, U$785, U$833, U$881, U$929, U$977, U$1025, U$1073, U$1121, U$1169, U$1217, U$1265, U$1313, U$1361, U$1409, U$1457, U$1505, U$1553, U$1601, U$1649, U$1697, U$1745, U$1793, U$1841, U$1889: PS114
U$34, U$66, U$114, U$162, U$210, U$258, U$306, U$354, U$402, U$450, U$498, U$546, U$594, U$642, U$690, U$738, U$786, U$834, U$882, U$930, U$978, U$1026, U$1074, U$1122, U$1170, U$1218, U$1266, U$1314, U$1362, U$1410, U$1458, U$1506, U$1554, U$1602, U$1650, U$1698, U$1746, U$1794, U$1842, U$1890: PS015
U$35, U$92, U$140, U$188, U$236, U$284, U$332, U$380, U$428, U$476, U$524, U$572, U$620, U$668, U$716, U$764, U$812, U$860, U$908, U$956, U$1004, U$1052, U$1100, U$1148, U$1196, U$1244, U$1292, U$1340, U$1388, U$1436, U$1484, U$1532, U$1580, U$1628, U$1676, U$1724, U$1772, U$1820, U$1868, U$1916: TXO0
U$39, U$67, U$115, U$163, U$211, U$259, U$307, U$355, U$403, U$451, U$499, U$547, U$595, U$643, U$691, U$739, U$787, U$835, U$883, U$931, U$979, U$1027, U$1075, U$1123, U$1171, U$1219, U$1267, U$1315, U$1363, U$1411, U$1459, U$1507, U$1555, U$1603, U$1651, U$1699, U$1747, U$1795, U$1843, U$1891: UART8
U$40, U$68, U$116, U$164, U$212, U$260, U$308, U$356, U$404, U$452, U$500, U$548, U$596, U$644, U$692, U$740, U$788, U$836, U$884, U$932, U$980, U$1028, U$1076, U$1124, U$1172, U$1220, U$1268, U$1316, U$1364, U$1412, U$1460, U$1508, U$1556, U$1604, U$1652, U$1700, U$1748, U$1796, U$1844, U$1892: GRN10
U$41, U$69, U$117, U$165, U$213, U$261, U$309, U$357, U$405, U$453, U$501, U$549, U$597, U$645, U$693, U$741, U$789, U$837, U$885, U$933, U$981, U$1029, U$1077, U$1125, U$1173, U$1221, U$1269, U$1317, U$1365, U$1413, U$1461, U$1509, U$1557, U$1605, U$1653, U$1701, U$1749, U$1797, U$1845, U$1893: BLK9
U$42, U$43, U$79, U$80, U$127, U$128, U$175, U$176, U$223, U$224, U$271, U$272, U$319, U$320, U$367, U$368, U$415, U$416, U$463, U$464, U$511, U$512, U$559, U$560, U$607, U$608, U$655, U$656, U$703, U$704, U$751, U$752, U$799, U$800, U$847, U$848, U$895, U$896, U$943, U$944, U$991, U$992, U$1039, U$1040, U$1087, U$1088, U$1135, U$1136, U$1183, U$1184, U$1231, U$1232, U$1279, U$1280, U$1327, U$1328, U$1375, U$1376, U$1423, U$1424, U$1471, U$1472, U$1519, U$1520, U$1567, U$1568, U$1615, U$1616, U$1663, U$1664, U$1711, U$1712, U$1759, U$1760, U$1807, U$1808, U$1855, U$1856, U$1903, U$1904: GND1
U$44, U$70, U$118, U$166, U$214, U$262, U$310, U$358, U$406, U$454, U$502, U$550, U$598, U$646, U$694, U$742, U$790, U$838, U$886, U$934, U$982, U$1030, U$1078, U$1126, U$1174, U$1222, U$1270, U$1318, U$1366, U$1414, U$1462, U$1510, U$1558, U$1606, U$1654, U$1702, U$1750, U$1798, U$1846, U$1894: BNO080_IMU11
U$46, U$71, U$119, U$167, U$215, U$263, U$311, U$359, U$407, U$455, U$503, U$551, U$599, U$647, U$695, U$743, U$791, U$839, U$887, U$935, U$983, U$1031, U$1079, U$1127, U$1175, U$1223, U$1271, U$1319, U$1367, U$1415, U$1463, U$1511, U$1559, U$1607, U$1655, U$1703, U$1751, U$1799, U$1847, U$1895: BNO08012
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

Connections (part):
3.3V: C2.1, C4.1, D1.A, J1.3, J2.2, J3.2, J4.2, J6.2, R1.2, R3.2, R6.2, R9.2, R10.2, SJ1.2, SJ3.1, SJ4.1, U2.3, U2.28
3.3V1: C6.1, C8.1, D2.A, J9.2, J10.2, J11.2, J12.2, J14.3, R4.2, R5.2, R11.2, R16.2, R17.2, SJ6.1, SJ7.1, SJ8.2, U1.3, U1.28
3.3V2: C11.1, C13.1, D3.A, J17.2, J18.2, J19.2, J20.2, J22.3, R21.2, R22.2, R23.2, R26.2, R27.2, SJ10.1, SJ11.1, SJ12.2, U3.3, U3.28
3.3V3: C16.1, C18.1, D4.A, J25.2, J26.2, J27.2, J28.2, J30.3, R31.2, R32.2, R33.2, R36.2, R37.2, SJ14.1, SJ15.1, SJ16.2, U4.3, U4.28
3.3V4: C21.1, C23.1, D5.A, J33.2, J34.2, J35.2, J36.2, J38.3, R41.2, R42.2, R43.2, R46.2, R47.2, SJ18.1, SJ19.1, SJ20.2, U5.3, U5.28
3.3V5: C26.1, C28.1, D6.A, J41.2, J42.2, J43.2, J44.2, J46.3, R51.2, R52.2, R53.2, R56.2, R57.2, SJ22.1, SJ23.1, SJ24.2, U6.3, U6.28
3.3V6: C31.1, C33.1, D7.A, J49.2, J50.2, J51.2, J52.2, J54.3, R61.2, R62.2, R63.2, R66.2, R67.2, SJ26.1, SJ27.1, SJ28.2, U7.3, U7.28
3.3V7: C36.1, C38.1, D8.A, J57.2, J58.2, J59.2, J60.2, J62.3, R71.2, R72.2, R73.2, R76.2, R77.2, SJ30.1, SJ31.1, SJ32.2, U8.3, U8.28
3.3V8: C41.1, C43.1, D9.A, J65.2, J66.2, J67.2, J68.2, J70.3, R81.2, R82.2, R83.2, R86.2, R87.2, SJ34.1, SJ35.1, SJ36.2, U9.3, U9.28
3.3V9: C46.1, C48.1, D10.A, J73.2, J74.2, J75.2, J76.2, J78.3, R91.2, R92.2, R93.2, R96.2, R97.2, SJ38.1, SJ39.1, SJ40.2, U10.3, U10.28
3.3V10: C51.1, C53.1, D11.A, J81.2, J82.2, J83.2, J84.2, J86.3, R101.2, R102.2, R103.2, R106.2, R107.2, SJ42.1, SJ43.1, SJ44.2, U11.3, U11.28
3.3V11: C56.1, C58.1, D12.A, J89.2, J90.2, J91.2, J92.2, J94.3, R111.2, R112.2, R113.2, R116.2, R117.2, SJ46.1, SJ47.1, SJ48.2, U12.3, U12.28
3.3V12: C61.1, C63.1, D13.A, J97.2, J98.2, J99.2, J100.2, J102.3, R121.2, R122.2, R123.2, R126.2, R127.2, SJ50.1, SJ51.1, SJ52.2, U13.3, U13.28
3.3V13: C66.1, C68.1, D14.A, J105.2, J106.2, J107.2, J108.2, J110.3, R131.2, R132.2, R133.2, R136.2, R137.2, SJ54.1, SJ55.1, SJ56.2, U14.3, U14.28
3.3V14: C71.1, C73.1, D15.A, J113.2, J114.2, J115.2, J116.2, J118.3, R141.2, R142.2, R143.2, R146.2, R147.2, SJ58.1, SJ59.1, SJ60.2, U15.3, U15.28
3.3V15: C76.1, C78.1, D16.A, J121.2, J122.2, J123.2, J124.2, J126.3, R151.2, R152.2, R153.2, R156.2, R157.2, SJ62.1, SJ63.1, SJ64.2, U16.3, U16.28
3.3V16: C81.1, C83.1, D17.A, J129.2, J130.2, J131.2, J132.2, J134.3, R161.2, R162.2, R163.2, R166.2, R167.2, SJ66.1, SJ67.1, SJ68.2, U17.3, U17.28
3.3V17: C86.1, C88.1, D18.A, J137.2, J138.2, J139.2, J140.2, J142.3, R171.2, R172.2, R173.2, R176.2, R177.2, SJ70.1, SJ71.1, SJ72.2, U18.3, U18.28
3.3V18: C91.1, C93.1, D19.A, J145.2, J146.2, J147.2, J148.2, J150.3, R181.2, R182.2, R183.2, R186.2, R187.2, SJ74.1, SJ75.1, SJ76.2, U19.3, U19.28
3.3V19: C96.1, C98.1, D20.A, J153.2, J154.2, J155.2, J156.2, J158.3, R191.2, R192.2, R193.2, R196.2, R197.2, SJ78.1, SJ79.1, SJ80.2, U20.3, U20.28
3.3V20: C101.1, C103.1, D21.A, J161.2, J162.2, J163.2, J164.2, J166.3, R201.2, R202.2, R203.2, R206.2, R207.2, SJ82.1, SJ83.1, SJ84.2, U21.3, U21.28
3.3V21: C106.1, C108.1, D22.A, J169.2, J170.2, J171.2, J172.2, J174.3, R211.2, R212.2, R213.2, R216.2, R217.2, SJ86.1, SJ87.1, SJ88.2, U22.3, U22.28
3.3V22: C111.1, C113.1, D23.A, J177.2, J178.2, J179.2, J180.2, J182.3, R221.2, R222.2, R223.2, R226.2, R227.2, SJ90.1, SJ91.1, SJ92.2, U23.3, U23.28
3.3V23: C116.1, C118.1, D24.A, J185.2, J186.2, J187.2, J188.2, J190.3, R231.2, R232.2, R233.2, R236.2, R237.2, SJ94.1, SJ95.1, SJ96.2, U24.3, U24.28
3.3V24: C121.1, C123.1, D25.A, J193.2, J194.2, J195.2, J196.2, J198.3, R241.2, R242.2, R243.2, R246.2, R247.2, SJ98.1, SJ99.1, SJ100.2, U25.3, U25.28
3.3V25: C126.1, C128.1, D26.A, J201.2, J202.2, J203.2, J204.2, J206.3, R251.2, R252.2, R253.2, R256.2, R257.2, SJ102.1, SJ103.1, SJ104.2, U26.3, U26.28
3.3V26: C131.1, C133.1, D27.A, J209.2, J210.2, J211.2, J212.2, J214.3, R261.2, R262.2, R263.2, R266.2, R267.2, SJ106.1, SJ107.1, SJ108.2, U27.3, U27.28
3.3V27: C136.1, C138.1, D28.A, J217.2, J218.2, J219.2, J220.2, J222.3, R271.2, R272.2, R273.2, R276.2, R277.2, SJ110.1, SJ111.1, SJ112.2, U28.3, U28.28
3.3V28: C141.1, C143.1, D29.A, J225.2, J226.2, J227.2, J228.2, J230.3, R281.2, R282.2, R283.2, R286.2, R287.2, SJ114.1, SJ115.1, SJ116.2, U29.3, U29.28
3.3V29: C146.1, C148.1, D30.A, J233.2, J234.2, J235.2, J236.2, J238.3, R291.2, R292.2, R293.2, R296.2, R297.2, SJ118.1, SJ119.1, SJ120.2, U30.3, U30.28
3.3V30: C151.1, C153.1, D31.A, J241.2, J242.2, J243.2, J244.2, J246.3, R301.2, R302.2, R303.2, R306.2, R307.2, SJ122.1, SJ123.1, SJ124.2, U31.3, U31.28
3.3V31: C156.1, C158.1, D32.A, J249.2, J250.2, J251.2, J252.2, J254.3, R311.2, R312.2, R313.2, R316.2, R317.2, SJ126.1, SJ127.1, SJ128.2, U32.3, U32.28
3.3V32: C161.1, C163.1, D33.A, J257.2, J258.2, J259.2, J260.2, J262.3, R321.2, R322.2, R323.2, R326.2, R327.2, SJ130.1, SJ131.1, SJ132.2, U33.3, U33.28
3.3V33: C166.1, C168.1, D34.A, J265.2, J266.2, J267.2, J268.2, J270.3, R331.2, R332.2, R333.2, R336.2, R337.2, SJ134.1, SJ135.1, SJ136.2, U34.3, U34.28
3.3V34: C171.1, C173.1, D35.A, J273.2, J274.2, J275.2, J276.2, J278.3, R341.2, R342.2, R343.2, R346.2, R347.2, SJ138.1, SJ139.1, SJ140.2, U35.3, U35.28
3.3V35: C176.1, C178.1, D36.A, J281.2, J282.2, J283.2, J284.2, J286.3, R351.2, R352.2, R353.2, R356.2, R357.2, SJ142.1, SJ143.1, SJ144.2, U36.3, U36.28
3.3V36: C181.1, C183.1, D37.A, J289.2, J290.2, J291.2, J292.2, J294.3, R361.2, R362.2, R363.2, R366.2, R367.2, SJ146.1, SJ147.1, SJ148.2, U37.3, U37.28
3.3V37: C186.1, C188.1, D38.A, J297.2, J298.2, J299.2, J300.2, J302.3, R371.2, R372.2, R373.2, R376.2, R377.2, SJ150.1, SJ151.1, SJ152.2, U38.3, U38.28
3.3V38: C191.1, C193.1, D39.A, J305.2, J306.2, J307.2, J308.2, J310.3, R381.2, R382.2, R383.2, R386.2, R387.2, SJ154.1, SJ155.1, SJ156.2, U39.3, U39.28
3.3V39: C196.1, C198.1, D40.A, J313.2, J314.2, J315.2, J316.2, J318.3, R391.2, R392.2, R393.2, R396.2, R397.2, SJ158.1, SJ159.1, SJ160.2, U40.3, U40.28
!BOOT: J5.1, R6.1, U2.4
!BOOT1: J15.1, R11.1, U1.4
!BOOT2: J23.1, R23.1, U3.4
!BOOT3: J31.1, R33.1, U4.4
!BOOT4: J39.1, R43.1, U5.4
!BOOT5: J47.1, R53.1, U6.4
!BOOT6: J55.1, R63.1, U7.4
!BOOT7: J63.1, R73.1, U8.4
!BOOT8: J71.1, R83.1, U9.4
!BOOT9: J79.1, R93.1, U10.4
!BOOT10: J87.1, R103.1, U11.4
!BOOT11: J95.1, R113.1, U12.4
!BOOT12: J103.1, R123.1, U13.4
!BOOT13: J111.1, R133.1, U14.4
!BOOT14: J119.1, R143.1, U15.4
!BOOT15: J127.1, R153.1, U16.4
!BOOT16: J135.1, R163.1, U17.4
!BOOT17: J143.1, R173.1, U18.4
!BOOT18: J151.1, R183.1, U19.4
!BOOT19: J159.1, R193.1, U20.4
!BOOT20: J167.1, R203.1, U21.4
!BOOT21: J175.1, R213.1, U22.4
!BOOT22: J183.1, R223.1, U23.4
!BOOT23: J191.1, R233.1, U24.4
!BOOT24: J199.1, R243.1, U25.4
!BOOT25: J207.1, R253.1, U26.4
!BOOT26: J215.1, R263.1, U27.4
!BOOT27: J223.1, R273.1, U28.4
!BOOT28: J231.1, R283.1, U29.4
!BOOT29: J239.1, R293.1, U30.4
!BOOT30: J247.1, R303.1, U31.4
!BOOT31: J255.1, R313.1, U32.4
!BOOT32: J263.1, R323.1, U33.4
!BOOT33: J271.1, R333.1, U34.4
!BOOT34: J279.1, R343.1, U35.4
!BOOT35: J287.1, R353.1, U36.4
!BOOT36: J295.1, R363.1, U37.4
!BOOT37: J303.1, R373.1, U38.4
!BOOT38: J311.1, R383.1, U39.4
!BOOT39: J319.1, R393.1, U40.4
!CS: J6.6, U2.18
!CS1: J12.6, U1.18
!CS2: J20.6, U3.18
!CS3: J28.6, U4.18
!CS4: J36.6, U5.18
!CS5: J44.6, U6.18
!CS6: J52.6, U7.18
!CS7: J60.6, U8.18
!CS8: J68.6, U9.18
!CS9: J76.6, U10.18
!CS10: J84.6, U11.18
!CS11: J92.6, U12.18
!CS12: J100.6, U13.18
!CS13: J108.6, U14.18
!CS14: J116.6, U15.18
!CS15: J124.6, U16.18
!CS16: J132.6, U17.18
!CS17: J140.6, U18.18
!CS18: J148.6, U19.18
!CS19: J156.6, U20.18
!CS20: J164.6, U21.18
!CS21: J172.6, U22.18
!CS22: J180.6, U23.18
!CS23: J188.6, U24.18
!CS24: J196.6, U25.18
!CS25: J204.6, U26.18
!CS26: J212.6, U27.18
!CS27: J220.6, U28.18
!CS28: J228.6, U29.18
!CS29: J236.6, U30.18
!CS30: J244.6, U31.18
!CS31: J252.6, U32.18
!CS32: J260.6, U33.18
!CS33: J268.6, U34.18
!CS34: J276.6, U35.18
!CS35: J284.6, U36.18
!CS36: J292.6, U37.18
!CS37: J300.6, U38.18
!CS38: J308.6, U39.18
!CS39: J316.6, U40.18
!INT: J7.2, U2.14
!INT1: J13.2, U1.14
!INT2: J21.2, U3.14
!INT3: J29.2, U4.14
!INT4: J37.2, U5.14
!INT5: J45.2, U6.14
!INT6: J53.2, U7.14
!INT7: J61.2, U8.14
!INT8: J69.2, U9.14
!INT9: J77.2, U10.14
!INT10: J85.2, U11.14
!INT11: J93.2, U12.14
!INT12: J101.2, U13.14
!INT13: J109.2, U14.14
!INT14: J117.2, U15.14
!INT15: J125.2, U16.14
!INT16: J133.2, U17.14
!INT17: J141.2, U18.14
!INT18: J149.2, U19.14
!INT19: J157.2, U20.14
!INT20: J165.2, U21.14
!INT21: J173.2, U22.14
!INT22: J181.2, U23.14
!INT23: J189.2, U24.14
!INT24: J197.2, U25.14
!INT25: J205.2, U26.14
!INT26: J213.2, U27.14
!INT27: J221.2, U28.14
!INT28: J229.2, U29.14
!INT29: J237.2, U30.14
!INT30: J245.2, U31.14
!INT31: J253.2, U32.14
!INT32: J261.2, U33.14
!INT33: J269.2, U34.14
!INT34: J277.2, U35.14
!INT35: J285.2, U36.14
!INT36: J293.2, U37.14
!INT37: J301.2, U38.14
!INT38: J309.2, U39.14
!INT39: J317.2, U40.14
!RST: J6.8, J7.1, R1.1, U2.11
!RST1: J12.8, J13.1, R4.1, U1.11
!RST2: J20.8, J21.1, R21.1, U3.11
!RST3: J28.8, J29.1, R31.1, U4.11
!RST4: J36.8, J37.1, R41.1, U5.11
!RST5: J44.8, J45.1, R51.1, U6.11
!RST6: J52.8, J53.1, R61.1, U7.11
!RST7: J60.8, J61.1, R71.1, U8.11
!RST8: J68.8, J69.1, R81.1, U9.11
!RST9: J76.8, J77.1, R91.1, U10.11
!RST10: J84.8, J85.1, R101.1, U11.11
!RST11: J92.8, J93.1, R111.1, U12.11
!RST12: J100.8, J101.1, R121.1, U13.11
!RST13: J108.8, J109.1, R131.1, U14.11
!RST14: J116.8, J117.1, R141.1, U15.11
!RST15: J124.8, J125.1, R151.1, U16.11
!RST16: J132.8, J133.1, R161.1, U17.11
!RST17: J140.8, J141.1, R171.1, U18.11
!RST18: J148.8, J149.1, R181.1, U19.11
!RST19: J156.8, J157.1, R191.1, U20.11
!RST20: J164.8, J165.1, R201.1, U21.11
!RST21: J172.8, J173.1, R211.1, U22.11
!RST22: J180.8, J181.1, R221.1, U23.11
!RST23: J188.8, J189.1, R231.1, U24.11
!RST24: J196.8, J197.1, R241.1, U25.11
!RST25: J204.8, J205.1, R251.1, U26.11
!RST26: J212.8, J213.1, R261.1, U27.11
!RST27: J220.8, J221.1, R271.1, U28.11
!RST28: J228.8, J229.1, R281.1, U29.11
!RST29: J236.8, J237.1, R291.1, U30.11
!RST30: J244.8, J245.1, R301.1, U31.11
!RST31: J252.8, J253.1, R311.1, U32.11
!RST32: J260.8, J261.1, R321.1, U33.11
!RST33: J268.8, J269.1, R331.1, U34.11
!RST34: J276.8, J277.1, R341.1, U35.11
!RST35: J284.8, J285.1, R351.1, U36.11
!RST36: J292.8, J293.1, R361.1, U37.11
!RST37: J300.8, J301.1, R371.1, U38.11
!RST38: J308.8, J309.1, R381.1, U39.11
!RST39: J316.8, J317.1, R391.1, U40.11
ADDR/MOSI: J6.5, R3.1, SJ2.2, U2.17
ADDR/MOSI1: J12.5, R5.1, SJ5.2, U1.17
ADDR/MOSI2: J20.5, R22.1, SJ9.2, U3.17
ADDR/MOSI3: J28.5, R32.1, SJ13.2, U4.17
ADDR/MOSI4: J36.5, R42.1, SJ17.2, U5.17
ADDR/MOSI5: J44.5, R52.1, SJ21.2, U6.17
ADDR/MOSI6: J52.5, R62.1, SJ25.2, U7.17
ADDR/MOSI7: J60.5, R72.1, SJ29.2, U8.17
ADDR/MOSI8: J68.5, R82.1, SJ33.2, U9.17
ADDR/MOSI9: J76.5, R92.1, SJ37.2, U10.17
ADDR/MOSI10: J84.5, R102.1, SJ41.2, U11.17
ADDR/MOSI11: J92.5, R112.1, SJ45.2, U12.17
ADDR/MOSI12: J100.5, R122.1, SJ49.2, U13.17
ADDR/MOSI13: J108.5, R132.1, SJ53.2, U14.17
ADDR/MOSI14: J116.5, R142.1, SJ57.2, U15.17
ADDR/MOSI15: J124.5, R152.1, SJ61.2, U16.17
ADDR/MOSI16: J132.5, R162.1, SJ65.2, U17.17
ADDR/MOSI17: J140.5, R172.1, SJ69.2, U18.17
ADDR/MOSI18: J148.5, R182.1, SJ73.2, U19.17
ADDR/MOSI19: J156.5, R192.1, SJ77.2, U20.17
ADDR/MOSI20: J164.5, R202.1, SJ81.2, U21.17
ADDR/MOSI21: J172.5, R212.1, SJ85.2, U22.17
ADDR/MOSI22: J180.5, R222.1, SJ89.2, U23.17
ADDR/MOSI23: J188.5, R232.1, SJ93.2, U24.17
ADDR/MOSI24: J196.5, R242.1, SJ97.2, U25.17
ADDR/MOSI25: J204.5, R252.1, SJ101.2, U26.17
ADDR/MOSI26: J212.5, R262.1, SJ105.2, U27.17
ADDR/MOSI27: J220.5, R272.1, SJ109.2, U28.17
ADDR/MOSI28: J228.5, R282.1, SJ113.2, U29.17
ADDR/MOSI29: J236.5, R292.1, SJ117.2, U30.17
ADDR/MOSI30: J244.5, R302.1, SJ121.2, U31.17
ADDR/MOSI31: J252.5, R312.1, SJ125.2, U32.17
ADDR/MOSI32: J260.5, R322.1, SJ129.2, U33.17
ADDR/MOSI33: J268.5, R332.1, SJ133.2, U34.17
ADDR/MOSI34: J276.5, R342.1, SJ137.2, U35.17
ADDR/MOSI35: J284.5, R352.1, SJ141.2, U36.17
ADDR/MOSI36: J292.5, R362.1, SJ145.2, U37.17
ADDR/MOSI37: J300.5, R372.1, SJ149.2, U38.17
ADDR/MOSI38: J308.5, R382.1, SJ153.2, U39.17
ADDR/MOSI39: J316.5, R392.1, SJ157.2, U40.17
CAP: C1.1, U2.9
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

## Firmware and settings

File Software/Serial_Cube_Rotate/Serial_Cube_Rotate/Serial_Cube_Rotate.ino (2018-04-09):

/*
  Using the BNO080 IMU
  By: Nathan Seidle
  SparkFun Electronics
  Date: December 21st, 2017
  License: This code is public domain but you buy me a beer if you use this and we meet someday (Beerware license).

  Feel like supporting our work? Buy a board from SparkFun!
  https://www.sparkfun.com/products/14586

  This example shows how to output the i/j/k/real parts of the rotation vector.
  https://en.wikipedia.org/wiki/Quaternions_and_spatial_rotation

  It takes about 1ms at 400kHz I2C to read a record from the sensor, but we are polling the sensor continually
  between updates from the sensor. Use the interrupt pin on the BNO080 breakout to avoid polling.

  Hardware Connections:
  Attach the Qwiic Shield to your Arduino/Photon/ESP32 or other
  Plug the sensor onto the shield
  Serial.print it out at 9600 baud to serial monitor.
*/

#include <Wire.h>

#include "SparkFun_BNO080_Arduino_Library.h"
BNO080 myIMU;

void setup()
{
  Serial.begin(9600);

  Wire.begin();
  Wire.setClock(400000); //Increase I2C data rate to 400kHz

  myIMU.begin();

  myIMU.enableRotationVector(50); //Send data update every 50ms
}

void loop()
{
  //Look for reports from the IMU
  if (myIMU.dataAvailable() == true)
  {
    float quatI = myIMU.getQuatI();
    float quatJ = myIMU.getQuatJ();
    float quatK = myIMU.getQuatK();
    float quatReal = myIMU.getQuatReal();

    Serial.print(quatReal, 2);
    Serial.print(F(","));
    Serial.print(quatI, 2);
    Serial.print(F(","));
    Serial.print(quatJ, 2);
    Serial.print(F(","));
    Serial.print(quatK, 2);

    Serial.println();
  }
}

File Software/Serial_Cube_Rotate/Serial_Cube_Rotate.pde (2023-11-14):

/**
 * <p>The ToxiclibsSupport class of the toxi.processing package provides various
 * shortcuts to directly use toxiclibs geometry datatypes with Processing style
 * drawing operations. Most of these are demonstrated in this example.</p>
 *
 * <p>UPDATES:
 * <ul>
 * <li>2010-12-30: added sphere/cylinder resolution modulation</li>
 * </ul></p>
 */
 
/* 
 * Copyright (c) 2010 Karsten Schmidt
 * 
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
 * http://creativecommons.org/licenses/LGPL/2.1/
 * 
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
 * You should have received a copy of the GNU Lesser General Public
 * License along with this library; if not, write to the Free Software
 * Foundation, Inc., 51 Franklin St, Fifth Floor, Boston, MA  02110-1301  USA
 */

//Download and manually install "toxiclibs-complete-0021.zip" => https://github.com/postspectacular/toxiclibs/releases/tag/0021
//Make sure to install in the correct path using Processing 3 => https://github.com/processing/processing/wiki/How-to-Install-a-Contributed-Library#manual-install
import toxi.geom.*;
import toxi.geom.mesh.*;
import toxi.math.waves.*;
import toxi.processing.*;
import processing.serial.*;

String myString = null;
Serial myPort;  // The serial port

ToxiclibsSupport gfx;

boolean waitFlag = true;

void setup() {
  size(600,600,P3D);
  gfx=new ToxiclibsSupport(this);
  
  background(255);
  noStroke();
  fill(200,200,200);
  
  // Print a list of connected serial devices in the console
  printArray(Serial.list());
  // Depending on where your BNO086 falls on this list, you
  // may need to change Serial.list()[0] to a different number
  myPort = new Serial(this, Serial.list()[6], 9600); //115200 baud seems to be too much for Processing?...
  //delay(50);
  myPort.clear();
  // Throw out the first chunk in case we caught it in the 
  // middle of a frame
  myString = myPort.readStringUntil(13);
  myString = null;  
}

void draw() {
  
  Quaternion RotQ = new Quaternion(1,0,0,0);
  float qMatrix[] = {0,0,0,0,0,0,0,0,0,0,0,0,0,0,0,0};
  PMatrix M1 = getMatrix();
  
  // When there is a sizeable amount of data on the serial port
  // read everything up to the first linefeed
  if(myPort.available() > 30){
    myString = myPort.readStringUntil(13);

    // generate an array of strings that contains each of the commas
    // separated values
    String inQuat[] = splitTokens(myString, ",");  
    
    // make sure that inQuat has a length of 4 before proceeding
    if (inQuat.length == 4){
      // build a Quaternion from inQuat[] array
      RotQ = new Quaternion(float(inQuat[0]), float(inQuat[1]), float(inQuat[2]),float(inQuat[3]));

      RotQ.toMatrix4x4().toFloatArray(qMatrix);

      M1.set(
      qMatrix[0], 
      qMatrix[1], 
      qMatrix[2], 
      qMatrix[3], 
      qMatrix[4], 
      qMatrix[5], 
      qMatrix[6], 
      qMatrix[7], 
      qMatrix[8], 
      qMatrix[9], 
      qMatrix[10], 
      qMatrix[11], 
      qMatrix[12], 
      qMatrix[13], 
      qMatrix[14], 
      qMatrix[15]
      );

      AABB cube;

      background(255);

      // Set some mood lighting
      ambientLight(128, 128, 128);
      directionalLight(128, 128, 128, 0, 0, 1);
      lightFalloff(1, 0, 0);
      lightSpecular(0, 0, 0);

      // Get to the middle of the screen
      translate(width/2,height/2,0);

      // Do some rotates to get oriented "behind" the device
      rotateX(-PI/2);

      // Apply the Matrix that we generated from our IMU Quaternion
      applyMatrix(M1);

      // Draw the Cube from a 3D Bounding Box
      cube=new AABB(new Vec3D(0,0,0),new Vec3D(100,100,100));
      gfx.box(cube);
    }
  }else{
    if(waitFlag){
    textSize(32);
    text("Waiting for quaternions to chew on...", 10, 30); 
    waitFlag = false;}
  }
}

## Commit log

2018-04-11 added bno080 to sfe lib
    [Qwiic_IMU_Bonobo.brd, Qwiic_IMU_Bonobo.sch]
2018-04-12 adding Nates BNO080
    [Qwiic_IMU_Bonobo.brd, Qwiic_IMU_Bonobo.sch]
2018-04-13 updated to Nates BNO080
    [Qwiic_IMU_Bonobo.brd, Qwiic_IMU_Bonobo.sch]
2018-04-13 pre review
    [Qwiic_IMU_Bonobo.brd, Qwiic_IMU_Bonobo.sch]
2018-04-13 post design review
    [Qwiic_IMU_Bonobo.brd, Qwiic_IMU_Bonobo.sch]
2018-04-13 Adding panel files
    [Qwiic_IMU_Bonobo-Panel.brd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]
2018-04-24 fixed rotation in processing sketch
    [Serial_Cube_Rotate.pde]
2018-11-25 Added an if statement to check if inQuat length is 4 before proceeding. Formatting.
    Without an if statement that checks the length of inQuat, an ArrayIndexOutOfBoundsException occasionally occurs. This is because the data retrieved from the sensor is not guaranteed to be 4 tokens lo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

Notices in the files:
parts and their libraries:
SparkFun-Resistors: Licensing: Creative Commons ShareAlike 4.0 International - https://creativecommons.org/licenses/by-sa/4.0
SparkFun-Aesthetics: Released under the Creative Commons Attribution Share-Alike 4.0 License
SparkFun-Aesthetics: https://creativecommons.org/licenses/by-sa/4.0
